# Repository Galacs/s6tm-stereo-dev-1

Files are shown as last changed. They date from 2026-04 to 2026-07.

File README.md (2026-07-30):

# S6TM Stereo Dev 1

ESP32S3 based stereo audio developement board with oled display

## IC List

- ESP32-S3FH4R2 (Main MCU)
- x4 LDL212 (LDOs)
- LM74502H (RPP, OCP)
- TPS629330 (5V out of audio SMPS)
- TLV320AIC (CODEC)
- TPA3116D2 (2x 30W audio amplifier)
- TPA3116D2 (OLED display)

## Top preview



## Preview 3d render



## Pictures

## Pin definitions

```c
#define SD_DAT0_PIN 33
#define SD_DAT1_PIN 47
#define SD_DAT2_PIN 37
#define SD_DAT3_PIN 36
#define SD_CLK_PIN 34
#define SD_CMD_PIN 35

#define SW_A_PIN 2
#define BTN_A_PIN 4
#define BTN_B_PIN 3

#define PG_PIN 5
#define VSNS_PIN 6

#define I2C_SDA_PIN 8
#define I2C_SCL_PIN 7

#define ENC_A_PIN 38
#define ENC_B_PIN 39
#define ENC_SW 40

#define FAULTZ_PIN 17
#define MUTE_PIN 21

#define GPIO1_PIN 15
#define RESET_PIN 16
#define BCLK_PIN 10
#define DOUT_PIN 13
#define DIN_PIN 12
#define MCLK_PIN 9
#define WCLK_PIN 11
```

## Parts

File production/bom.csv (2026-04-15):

Designator | Footprint | Quantity | Value | LCSC Part #
AE1 | Johanson_2450AT18x100 | 1 | Antenna | C127629
C1, C3 | 0402 | 2 | 1p2 | C76899
C10, C14, C22, C46, C47, C48, C6, C8, C9 | 0402 | 9 | 0u1 | C307331
C11, C24, C28, C29, C32, C33, C4, C40, C41, C42, C43, C54, C55, C56, C57, C62, C7 | 0402 | 17 | 1u | C52923
C12, C13 | 0402 | 2 | 12p | C1547
C15, C16, C17, C18, C19, C20, C5 | 0402 | 7 | 10u | C15525
C21, C23, C44, C45, C50, C51, C52, C53 | 0805 | 8 | 10u | C440198
C25, C26 | CP_Elec_8x10 | 2 | 220u | C136294
C27, C30, C31, C34, C35, C36, C37, C38, C39, C49 | 0402 | 10 | 220n | C16772
C58, C59, C60, C61 | 0402 | 4 | 4u7 | C23733
D1 | D_SOD-123 | 1 | BZT52B3V3 | C19077392
D10, D6, D8 | Diode_DFN1006 | 3 | H5VU10U | C22395519
D11, D13 | 0805 | 2 | RED | NCD0805R1
D12 | D_SMB | 1 | D_TVS | C2925441
D14, D9 | D_SMA | 2 | D_Schottky | C22452
D2, D3, D5 | 0805 | 3 | GREEN | C2297
D4, D7 | 0603 | 2 | WHITE | C2290
J1 | microSD_Hanbo_TF012 | 1 | Micro_SD_Card_Det1 | C410350
J3 | USB_C_Receptacle_HRO_TYPE-C-31-M-12 | 1 | USB_C_Receptacle_USB2.0_14P | C393939
J4 | JST_PH_B2B-PH-K_1x02_P2.00mm_Vertical | 1 | Conn_01x02
J5 | Jack_3.5mm_KoreanHropartsElec_PJ-320D-4A_Horizontal | 1 | AudioJack4 | C521460
J6, J7 | JST_XH_B2B-XH-A_1x02_P2.50mm_Vertical | 2 | Conn_01x02
L1 | 0402 | 1 | 6n8 | C77110
L10 | L_Sunlord_MWSA0402S | 1 | 3u3 | C167207
L3, L4 | 0402 | 2 | 2n7 | C77108
L5 | 0402 | 1 | 24n | C167472
L6, L7, L8, L9 | L_Vishay_IHLP-4040 | 4 | 10u | C845065
MK1 | JST_PH_B2B-PH-K_1x02_P2.00mm_Vertical | 1 | Microphone
Q1, Q2 | Vishay_PowerPAK_1212-8_Single | 2 | Q_NMOS | C111309
R1 | 0402 | 1 | 0 | C17168
R10, R11, R12, R18, R19, R7, R8, R9 | 0402 | 8 | 22 | C25092
R13, R14, R16, R17, R2, R20, R22, R3, R34, R35, R4, R40, R44, R45, R47, R5, R6 | 0402 | 17 | 10k | C25744
R15 | 0402 | 1 | 470 | C25117
R21, R42 | 0402 | 2 | 1k | C11702
R23, R24, R25, R26, R27, R28, R29, R30, R36, R43 | 0402 | 10 | 5k1 | C25905
R31 | 0402 | 1 | 2k2 | C25879
R33 | 0603 | 1 | 5k6 | C23189
R37 | 0402 | 1 | 100k | C25741
R38 | 0603 | 1 | 3k6 | C22980
R39 | 0402 | 1 | 52k3 | C26982
R41 | 0402 | 1 | 2k4 | C25882
R46, R48 | 0402 | 2 | 5k6 | C25908
SW1 | SW_SPDT_Shouhan_MSK12C02 | 1 | SW_SPDT | C431540
SW2, SW3 | SW_SPST_Omron_B3F-40xx | 2 | SW_Push | C84931
SW5, SW6 | SW_SPST_TS-1088-xR020 | 2 | SW_Push | C720477
SW7 | RotaryEncoder_Alps_EC11E-Switch_Vertical_H20mm | 1 | RotaryEncoder_Switch | C370970
TP10, TP11, TP13, TP14, TP19, TP3, TP4, TP5, TP6, TP7, TP8, TP9 | TestPoint_Keystone_5015_Micro_Mini | 12 | TestPoint | C2906768
U1 | QFN-56-1EP_7x7mm_P0.4mm_EP4x4mm_ThermalVias | 1 | ESP32-S3FN8 | C3013940
U10, U7, U8, U9 | DFN-6-1EP_2x2mm_P0.5mm_ST | 4 | LDL212PVR | C2969922
U3 | VQFN-32-1EP_5x5mm_P0.5mm_EP3.5x3.5mm | 1 | TLV320AIC3100 | C478458
U4 | HTSSOP-32-1EP_6.1x11mm_P0.65mm_EP5.2x11mm_Mask4.11x4.36mm_ThermalVias | 1 | TPA3118D2 | C46497
U5 | SOT-583-8 | 1 | TPS62933O | C6290372
U6 | SOT-23-THIN-8 | 1 | LM74502 | C3236215
Y1 | Crystal_SMD_2016-4Pin_2.0x1.6mm | 1 | 48M | C7206306

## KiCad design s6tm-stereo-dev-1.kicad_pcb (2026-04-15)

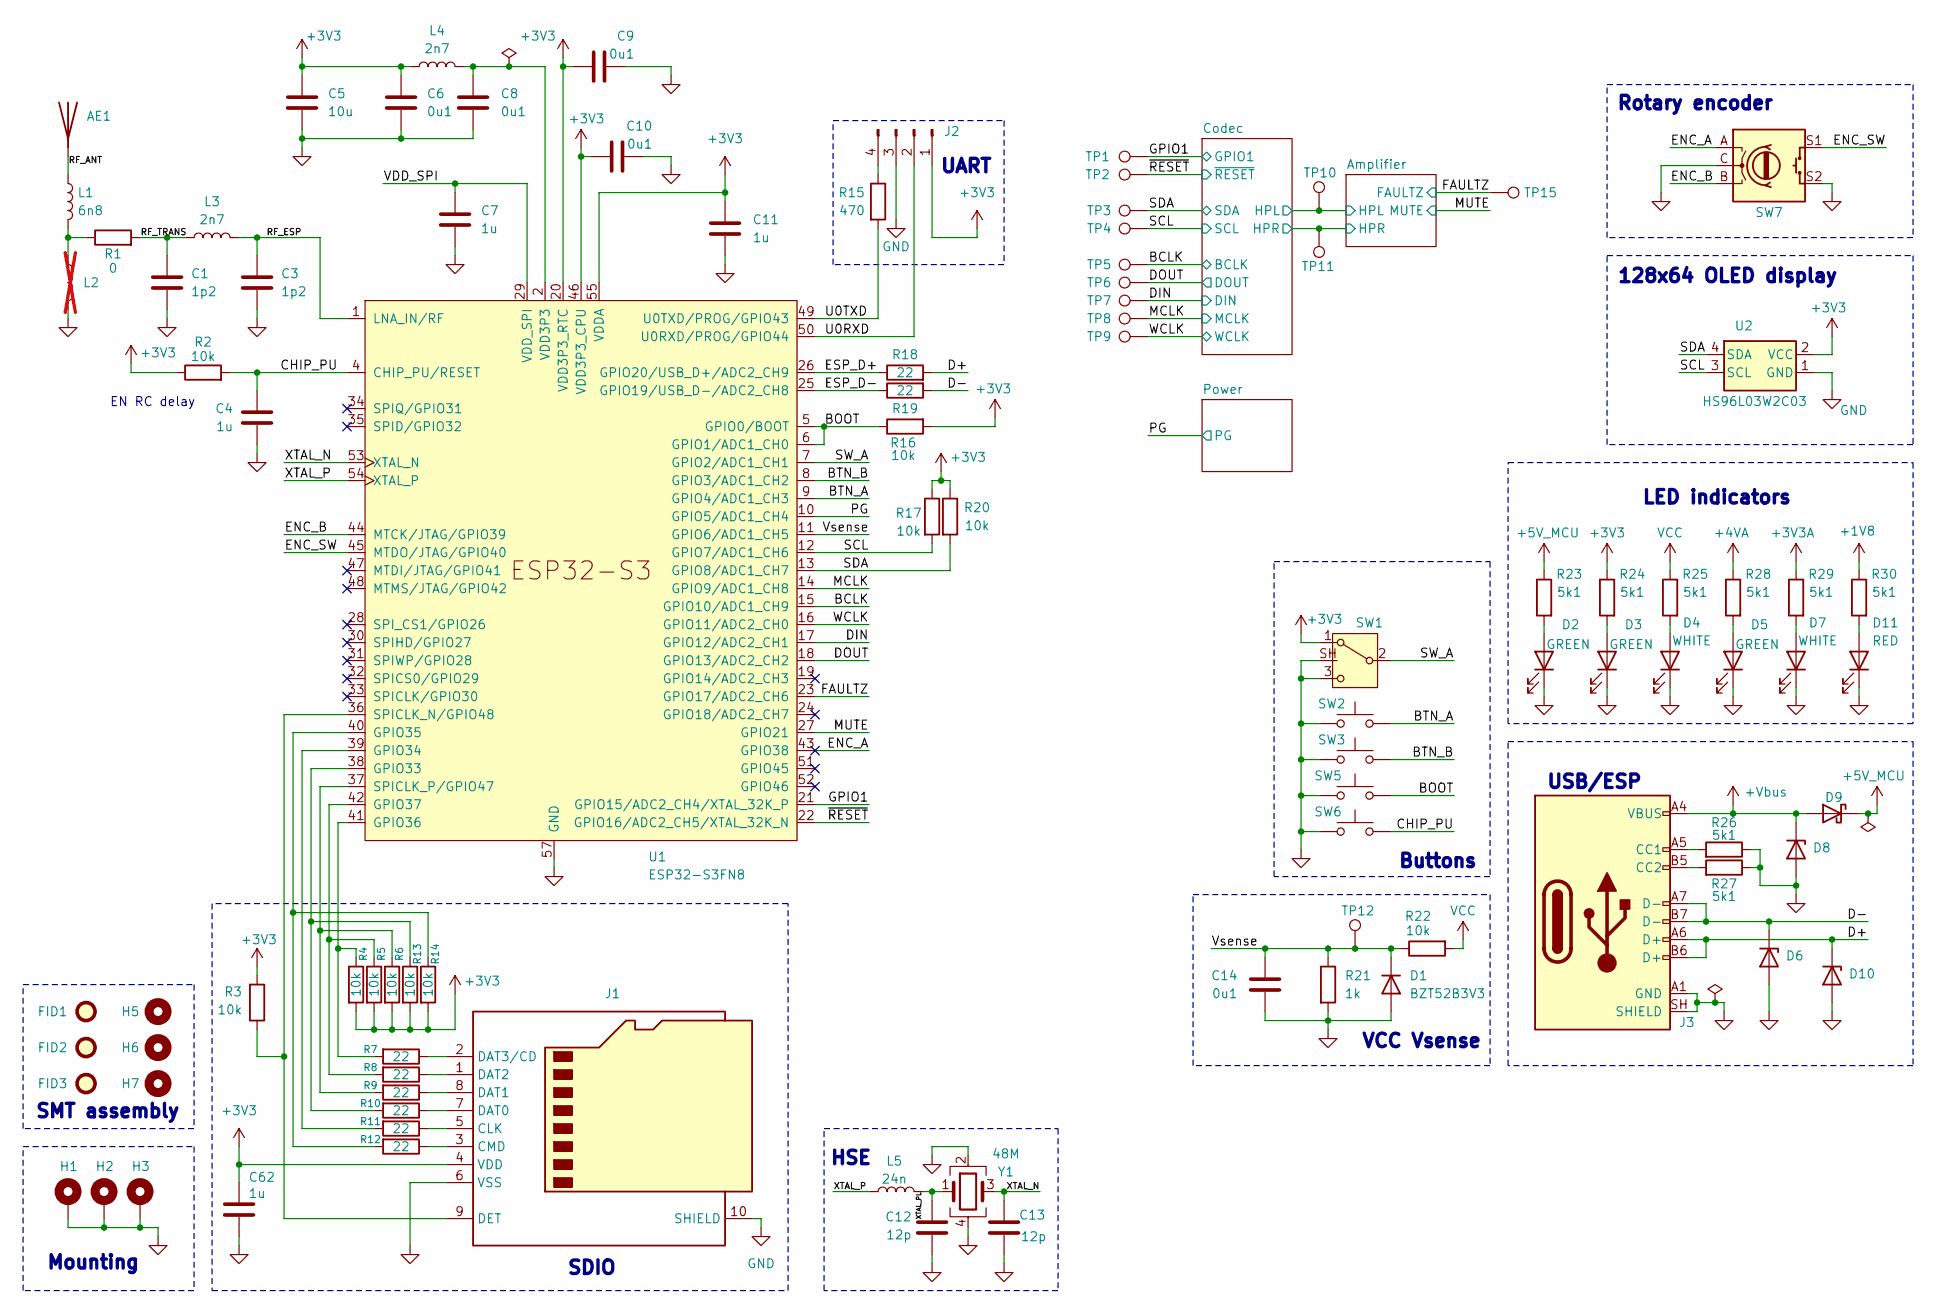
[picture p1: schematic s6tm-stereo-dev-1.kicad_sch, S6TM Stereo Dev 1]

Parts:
AE1: Antenna; Johanson_2450AT18x100; Manufacturer Part Number RFANT3216120A5T; JLCPCB Part # C127629
C1, C3: 1p2; C_0402_1005Metric; Manufacturer Part Number GJM1555C1H1R2WB01D; JLCPCB Part # C76899
C4, C7, C11, C62: 1u; C_0402_1005Metric; Manufacturer Part Number CL05A105KA5NQNC; JLCPCB Part # C52923
C5: 10u; C_0402_1005Metric; Manufacturer Part Number CL05A106MQ5NUNC; JLCPCB Part # C15525
C6, C8, C9, C10, C14: 0u1; C_0402_1005Metric; Manufacturer Part Number CL05B104KB54PNC; JLCPCB Part # C307331
C12, C13: 12p; C_0402_1005Metric; Manufacturer Part Number 0402CG120J500NT; JLCPCB Part # C1547
D1: BZT52B3V3; D_SOD-123; Manufacturer Part Number BZT52B3V3; JLCPCB Part # C19077392
D2, D3, D5: GREEN; LED_0805_2012Metric; Manufacturer Part Number KT-0805G; JLCPCB Part # C2297
D4, D7: WHITE; LED_0603_1608Metric; Manufacturer Part Number KT-0603W; JLCPCB Part # C2290
D6, D8, D10: H5VU10U; Diode_DFN1006; Manufacturer Part Number H5VU10U; JLCPCB Part # C22395519
D9: D_Schottky; D_SMA; Manufacturer Part Number SS54; JLCPCB Part # C22452
D11: RED; LED_0805_2012Metric; Manufacturer Part Number NCD0805R1; JLCPCB Part # NCD0805R1
FID1, FID2, FID3: Fiducial; Fiducial_1mm_Mask2mm
H1, H2, H3: MountingHole_Pad; MountingHole_3.2mm_M3_Pad_Via
H5, H6, H7: MountingHole; ToolingHole_1.152mm
J1: Micro_SD_Card_Det1; microSD_Hanbo_TF012; Manufacturer Part Number TF-012; JLCPCB Part # C410350
J2: Conn_01x04_Pin; PinHeader_1x04_P2.54mm_Vertical
J3: USB_C_Receptacle_USB2.0_14P; USB_C_Receptacle_HRO_TYPE-C-31-M-12; Manufacturer Part Number TYPE-C16PIN; JLCPCB Part # C393939
L1: 6n8; L_0402_1005Metric; Manufacturer Part Number LQG15HS6N8J02D; JLCPCB Part # C77110
L2: L; L_0402_1005Metric; not fitted
L3, L4: 2n7; L_0402_1005Metric; Manufacturer Part Number LQG15HS2N7S02D; JLCPCB Part # C77108
L5: 24n; L_0402_1005Metric; Manufacturer Part Number LQW15AN24NG00D; JLCPCB Part # C167472
R1: 0; R_0402_1005Metric; Manufacturer Part Number 0402WGF0000TCE; JLCPCB Part # C17168
R2, R3, R4, R5, R6, R13, R14, R16, R17, R20, R22: 10k; R_0402_1005Metric; Manufacturer Part Number 0402WGF1002TCE; JLCPCB Part # C25744
R7, R8, R9, R10, R11, R12, R18, R19: 22; R_0402_1005Metric; Manufacturer Part Number 0402WGF220JTCE; JLCPCB Part # C25092
R15: 470; R_0402_1005Metric; Manufacturer Part Number 0402WGF4700TCE; JLCPCB Part # C25117
R21: 1k; R_0402_1005Metric; Manufacturer Part Number 0402WGF1001TCE; JLCPCB Part # C11702
R23, R24, R25, R26, R27, R28, R29, R30: 5k1; R_0402_1005Metric; Manufacturer Part Number 0402WGF5101TCE; JLCPCB Part # C25905
SW1: SW_SPDT; SW_SPDT_Shouhan_MSK12C02; Manufacturer Part Number MSK12C02; JLCPCB Part # C431540
SW2, SW3: SW_Push; SW_SPST_Omron_B3F-40xx; Manufacturer Part Number B3F-4055; JLCPCB Part # C84931
SW5, SW6: SW_Push; SW_SPST_TS-1088-xR020; Manufacturer Part Number TS-1088-AR02016; JLCPCB Part # C720477
SW7: RotaryEncoder_Switch; RotaryEncoder_Alps_EC11E-Switch_Vertical_H20mm; Manufacturer Part Number EC11E15244G1; JLCPCB Part # C370970
TP1, TP2, TP12, TP15: TestPoint; TestPoint_Pad_D2.0mm
TP3, TP4, TP5, TP6, TP7, TP8, TP9, TP10, TP11: TestPoint; TestPoint_Keystone_5015_Micro_Mini; Manufacturer Part Number 5015; JLCPCB Part # C2906768
U1: ESP32-S3FN8; QFN-56-1EP_7x7mm_P0.4mm_EP4x4mm_ThermalVias; Manufacturer Part Number ESP32-S3FH4R2; JLCPCB Part # C3013940
U2: HS96L03W2C03
Y1: 48M; Crystal_SMD_2016-4Pin_2.0x1.6mm; Manufacturer Part Number R940000096; JLCPCB Part # C7206306

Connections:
+1V8: R30.1; also elsewhere on the board
+3V3: C5.1, C6.1, C9.1, C10.1, C11.1, C62.1, J1.4 (VDD), J2.1, L4.1, R2.1, R3.2, R4.2, R5.2, R6.2, R13.2, R14.2, R16.2, R17.1, R20.1, R24.1, SW1.1 (A), U1.20 (VDD3P3_RTC), U1.46 (VDD3P3_CPU), U1.55 (VDDA), U1.56 (VDDA), U2.2 (VCC); also elsewhere on the board
+3V3A: R29.1; also elsewhere on the board
+4VA: R28.1; also elsewhere on the board
+5V_MCU: D9.1 (K), R23.1; also elsewhere on the board
+Vbus: D8.1 (K), D9.2 (A), J3.A4 (VBUS), J3.A9 (VBUS), J3.B4 (VBUS), J3.B9 (VBUS)
/Amplifier/HPL: TP10.1 (1_1); also elsewhere on the board
/Amplifier/HPR: TP11.1 (1_1); also elsewhere on the board
/BCLK: TP5.1 (1_1), U1.15 (GPIO10/ADC1_CH9); also elsewhere on the board
/BOOT: R16.1, SW5.2, U1.5 (GPIO0/BOOT), U1.6 (GPIO1/ADC1_CH0)
/BTN_A: SW2.1, U1.9 (GPIO4/ADC1_CH3)
/BTN_B: SW3.1, U1.8 (GPIO3/ADC1_CH2)
/CHIP_PU: C4.1, R2.2, SW6.2, U1.4 (CHIP_PU/RESET)
/D+: D10.1 (K), J3.A6 (D+), J3.B6 (D+), R18.2
/D-: D6.1 (K), J3.A7 (D-), J3.B7 (D-), R19.2
/DIN: TP7.1 (1_1), U1.17 (GPIO12/ADC2_CH1); also elsewhere on the board
/DOUT: TP6.1 (1_1), U1.18 (GPIO13/ADC2_CH2); also elsewhere on the board
/ENC_A: SW7.A, U1.43 (GPIO38)
/ENC_B: SW7.B, U1.44 (MTCK/JTAG/GPIO39)
/ENC_SW: SW7.S1, U1.45 (MTDO/JTAG/GPIO40)
/ESP_D+: R18.1, U1.26 (GPIO20/USB_D+/ADC2_CH9)
/ESP_D-: R19.1, U1.25 (GPIO19/USB_D-/ADC2_CH8)
/FAULTZ: TP15.1 (1_1), U1.23 (GPIO17/ADC2_CH6); also elsewhere on the board
/GPIO1: TP1.1 (1_1), U1.21 (GPIO15/ADC2_CH4/XTAL_32K_P); also elsewhere on the board
/MCLK: TP8.1 (1_1), U1.14 (GPIO9/ADC1_CH8); also elsewhere on the board
/MUTE: U1.27 (GPIO21); also elsewhere on the board
/PG: U1.10 (GPIO5/ADC1_CH4); also elsewhere on the board
/RF_ANT: AE1.1 (A_1), L1.1
/RF_ESP: C3.1, L3.2, U1.1 (LNA_IN/RF)
/RF_TRANS: C1.1, L3.1, R1.2
/SCL: R17.2, TP4.1 (1_1), U1.12 (GPIO7/ADC1_CH6), U2.3 (SCL); also elsewhere on the board
/SDA: R20.2, TP3.1 (1_1), U1.13 (GPIO8/ADC1_CH7), U2.4 (SDA); also elsewhere on the board
/SW_A: SW1.2 (B), U1.7 (GPIO2/ADC1_CH1)
/U0RXD: J2.2, U1.50 (U0RXD/PROG/GPIO44)
/U0TXD: R15.2, U1.49 (U0TXD/PROG/GPIO43)
/VDD_SPI: C7.1, U1.29 (VDD_SPI)
/Vsense: C14.1, D1.1 (K), R21.1, R22.1, TP12.1 (1_1), U1.11 (GPIO6/ADC1_CH5)
/WCLK: TP9.1 (1_1), U1.16 (GPIO11/ADC2_CH0); also elsewhere on the board
/XTAL_N: C13.1, U1.53 (XTAL_N), Y1.3
/XTAL_P: L5.1, U1.54 (XTAL_P)
/XTAL_PL: C12.2, L5.2, Y1.1
/~RESET: TP2.1 (1_1), U1.22 (GPIO16/ADC2_CH5/XTAL_32K_N); also elsewhere on the board
GND: C1.2, C3.2, C4.2, C5.2, C6.2, C7.2, C8.2, C9.2, C10.2, C11.2, C12.1, C13.2, C14.2, C62.2, D1.2 (A), D2.1 (K), D3.1 (K), D4.1 (K), D5.1 (K), D6.2 (A), D7.1 (K), D8.2 (A), D10.2 (A), D11.1 (K), H1.1 (1_1), H2.1 (1_1), H3.1 (1_1), J1.6 (VSS), J1.10 (SHIELD), J2.3, J3.A1 (GND), J3.A12 (GND), J3.B1 (GND), J3.B12 (GND), J3.SH (SHIELD), L2.2, R21.2, R26.1, R27.1, SW1.3 (C), SW1.SH, SW2.2, SW3.2, SW5.1, SW6.1, SW7.C, SW7.S2, U1.57 (GND), U2.1 (GND), Y1.2, Y1.4; also elsewhere on the board
unnamed: D2.2 (A), R23.2
unnamed: D3.2 (A), R24.2
unnamed: D4.2 (A), R25.2
unnamed: D5.2 (A), R28.2
unnamed: D7.2 (A), R29.2
unnamed: D11.2 (A), R30.2
unnamed: J1.5 (CLK), R11.1
unnamed: J1.3 (CMD), R12.1
unnamed: J1.7 (DAT0), R10.1
unnamed: J1.8 (DAT1), R9.1
unnamed: J1.1 (DAT2), R8.1
unnamed: J1.2 (DAT3/CD), R7.1
unnamed: J1.9 (DET), R3.1, U1.36 (SPICLK_N/GPIO48)
unnamed: J2.4, R15.1
unnamed: J3.A5 (CC1), R26.2
unnamed: J3.B5 (CC2), R27.2
unnamed: L1.2, L2.1, R1.1
unnamed: R10.2, R13.1, U1.38 (GPIO33)
unnamed: R11.2, U1.39 (GPIO34)
unnamed: R12.2, R14.1, U1.40 (GPIO35)
unnamed: R4.1, R7.2, U1.41 (GPIO36)
unnamed: R5.1, R8.2, U1.42 (GPIO37)
unnamed: R6.1, R9.2, U1.37 (SPICLK_P/GPIO47)
VCC: R22.2, R25.1; also elsewhere on the board
VDD3P3: C8.1, L4.2, U1.2 (VDD3P3), U1.3 (VDD3P3)

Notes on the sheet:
Mounting
Rotary encoder
HSE
UART
128x64 OLED display
SMT assembly
SDIO
EN RC delay
VCC Vsense
USB/ESP
Buttons
LED indicators

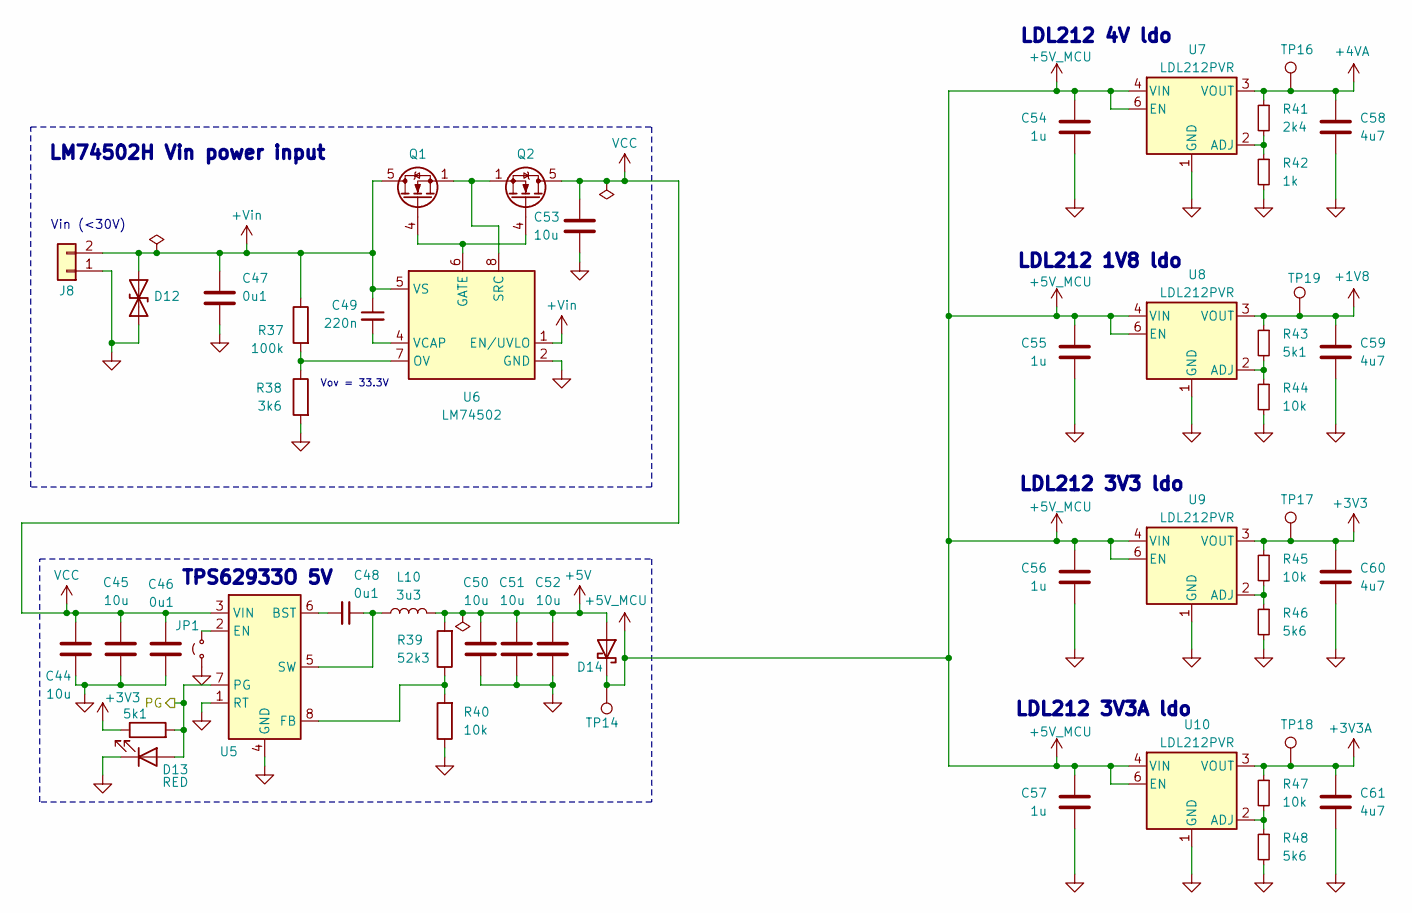
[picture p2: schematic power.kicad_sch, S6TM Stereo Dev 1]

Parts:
C44, C45, C50, C51, C52, C53: 10u; C_0805_2012Metric; Manufacturer Part Number GRM21BR61H106KE43L; JLCPCB Part # C440198
C46, C47, C48: 0u1; C_0402_1005Metric; Manufacturer Part Number CL05B104KB54PNC; JLCPCB Part # C307331
C49: 220n; C_0402_1005Metric; Manufacturer Part Number CL05B224KO5NNNC; JLCPCB Part # C16772
C54, C55, C56, C57: 1u; C_0402_1005Metric; Manufacturer Part Number CL05A105KA5NQNC; JLCPCB Part # C52923
C58, C59, C60, C61: 4u7; C_0402_1005Metric; Manufacturer Part Number CL05A475MP5NRNC; JLCPCB Part # C23733
D12: D_TVS; D_SMB; Manufacturer Part Number SMBJ30CA; JLCPCB Part # C2925441
D13: RED; LED_0805_2012Metric; Manufacturer Part Number NCD0805R1; JLCPCB Part # NCD0805R1
D14: D_Schottky; D_SMA; Manufacturer Part Number SS54; JLCPCB Part # C22452
J8: Conn_01x02; TerminalBlock_Phoenix_MKDS-1,5-2-5.08_1x02_P5.08mm_Horizont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
JP1: Jumper_2_Small_Open; PinHeader_1x02_P2.54mm_Vertical
L10: 3u3; L_Sunlord_MWSA0402S; Manufacturer Part Number FXL0420-3R3-M; JLCPCB Part # C167207
Q1, Q2: Q_NMOS; Vishay_PowerPAK_1212-8_Single; Manufacturer Part Number SIS412DN-T1-GE3; JLCPCB Part # C111309
R36, R43: 5k1; R_0402_1005Metric; Manufacturer Part Number 0402WGF5101TCE; JLCPCB Part # C25905
R37: 100k; R_0402_1005Metric; Manufacturer Part Number 0402WGF1003TCE; JLCPCB Part # C25741
R38: 3k6; R_0603_1608Metric; Manufacturer Part Number 0603WAF3601T5E; JLCPCB Part # C22980
R39: 52k3; R_0402_1005Metric; Manufacturer Part Number 0402WGF5232TCE; JLCPCB Part # C26982
R40, R44, R45, R47: 10k; R_0402_1005Metric; Manufacturer Part Number 0402WGF1002TCE; JLCPCB Part # C25744
R41: 2k4; R_0402_1005Metric; Manufacturer Part Number 0402WGF2401TCE; JLCPCB Part # C25882
R42: 1k; R_0402_1005Metric; Manufacturer Part Number 0402WGF1001TCE; JLCPCB Part # C11702
R46, R48: 5k6; R_0402_1005Metric; Manufacturer Part Number 0402WGF5601TCE; JLCPCB Part # C25908
TP14, TP19: TestPoint; TestPoint_Keystone_5015_Micro_Mini; Manufacturer Part Number 5015; JLCPCB Part # C2906768
TP16, TP17, TP18: TestPoint; TestPoint_Pad_D2.0mm
U5: TPS62933O; SOT-583-8; Manufacturer Part Number TPS62933ODRLR; JLCPCB Part # C6290372
U6: LM74502; SOT-23-THIN-8; Manufacturer Part Number LM74502DDFR; JLCPCB Part # C3236215
U7, U8, U9, U10: LDL212PVR; DFN-6-1EP_2x2mm_P0.5mm_ST; Manufacturer Part Number LDL212PVR; JLCPCB Part # C2969922

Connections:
+1V8: C59.1, R43.1, TP19.1 (1_1), U8.3 (VOUT); also elsewhere on the board
+3V3: C60.1, R36.1, R45.1, TP17.1 (1_1), U9.3 (VOUT); also elsewhere on the board
+3V3A: C61.1, R47.1, TP18.1 (1_1), U10.3 (VOUT); also elsewhere on the board
+4VA: C58.1, R41.1, TP16.1 (1_1), U7.3 (VOUT); also elsewhere on the board
+5V: C50.1, C51.1, C52.1, D14.2 (A), L10.2, R39.2
+5V_MCU: C54.1, C55.1, C56.1, C57.1, D14.1 (K), TP14.1 (1_1), U7.4 (VIN), U7.6 (EN), U8.4 (VIN), U8.6 (EN), U9.4 (VIN), U9.6 (EN), U10.4 (VIN), U10.6 (EN); also elsewhere on the board
+Vin: C47.1, C49.1, D12.2 (A2), J8.2, Q1.5 (D), R37.1, U6.1 (EN/UVLO), U6.5 (VS)
/PG: D13.2 (A), R36.2, U5.7 (PG); also elsewhere on the board
GND: C44.2, C45.2, C46.2, C47.2, C50.2, C51.2, C52.2, C53.2, C54.2, C55.2, C56.2, C57.2, C58.2, C59.2, C60.2, C61.2, D12.1 (A1), D13.1 (K), J8.1, JP1.1 (A), R38.2, R40.1, R42.2, R44.2, R46.2, R48.2, U5.1 (RT), U5.4 (GND), U6.2 (GND), U7.1 (GND), U8.1 (GND), U9.1 (GND), U10.1 (GND); also elsewhere on the board
unnamed: JP1.2 (B), U5.2 (EN)
unnamed: Q1.4 (G), Q2.4 (G), U6.6 (GATE)
unnamed: C48.2, U5.6 (BST)
unnamed: R39.1, R40.2, U5.8 (FB)
unnamed: C48.1, L10.1, U5.5 (SW)
unnamed: R37.2, R38.1, U6.7 (OV)
unnamed: Q1.1 (S), Q1.2 (S), Q1.3 (S), Q2.1 (S), Q2.2 (S), Q2.3 (S), U6.8 (SRC)
unnamed: C49.2, U6.4 (VCAP)
unnamed: R41.2, R42.1, U7.2 (ADJ)
unnamed: R43.2, R44.1, U8.2 (ADJ)
unnamed: R45.2, R46.1, U9.2 (ADJ)
unnamed: R47.2, R48.1, U10.2 (ADJ)
VCC: C44.1, C45.1, C46.1, C53.1, Q2.5 (D), U5.3 (VIN); also elsewhere on the board

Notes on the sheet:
LDL212 3V3A ldo
Vov = 33.3V
Vin (<30V)
TPS62933O 5V
LDL212 4V ldo
LDL212 1V8 ldo
LM74502H Vin power input
LDL212 3V3 ldo

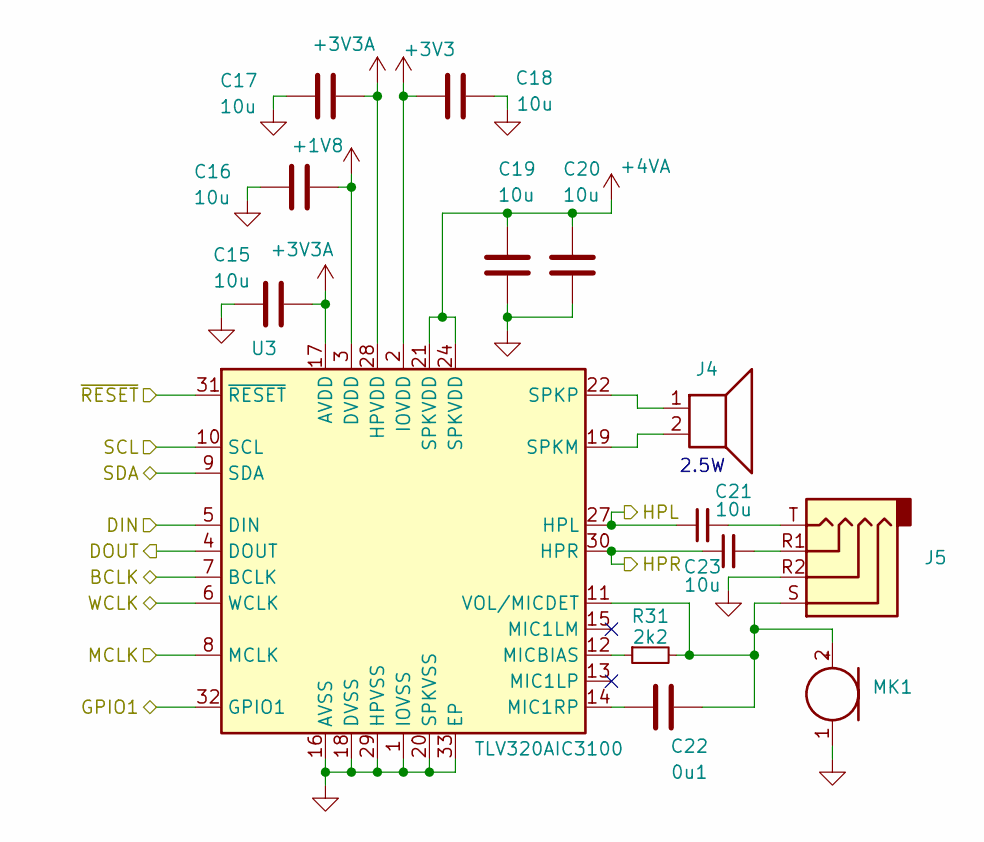
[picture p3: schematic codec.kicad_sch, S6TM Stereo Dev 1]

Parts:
C15, C16, C17, C18, C19, C20: 10u; C_0402_1005Metric; Manufacturer Part Number CL05A106MQ5NUNC; JLCPCB Part # C15525
C21, C23: 10u; C_0805_2012Metric; Manufacturer Part Number GRM21BR61H106KE43L; JLCPCB Part # C440198
C22: 0u1; C_0402_1005Metric; Manufacturer Part Number CL05B104KB54PNC; JLCPCB Part # C307331
J4: Conn_01x02; JST_PH_B2B-PH-K_1x02_P2.00mm_Vertical
J5: AudioJack4; Jack_3.5mm_KoreanHropartsElec_PJ-320D-4A_Horizontal; Manufacturer Part Number PJ-320D; JLCPCB Part # C521460
MK1: Microphone; JST_PH_B2B-PH-K_1x02_P2.00mm_Vertical
R31: 2k2; R_0402_1005Metric; Manufacturer Part Number 0402WGF2201TCE; JLCPCB Part # C25879
U3: TLV320AIC3100; VQFN-32-1EP_5x5mm_P0.5mm_EP3.5x3.5mm; Manufacturer Part Number TLV320AIC3100IRHBR; JLCPCB Part # C478458

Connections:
+1V8: C16.2, U3.3 (DVDD); also elsewhere on the board
+3V3: C18.2, U3.2 (IOVDD); also elsewhere on the board
+3V3A: C15.2, C17.2, U3.17 (AVDD), U3.28 (HPVDD); also elsewhere on the board
+4VA: C19.1, C20.1, U3.21 (SPKVDD), U3.24 (SPKVDD); also elsewhere on the board
/Amplifier/HPL: C21.1, U3.27 (HPL); also elsewhere on the board
/Amplifier/HPR: C23.1, U3.30 (HPR); also elsewhere on the board
/BCLK: U3.7 (BCLK); also elsewhere on the board
/DIN: U3.5 (DIN); also elsewhere on the board
/DOUT: U3.4 (DOUT); also elsewhere on the board
/GPIO1: U3.32 (GPIO1); also elsewhere on the board
/MCLK: U3.8 (MCLK); also elsewhere on the board
/SCL: U3.10 (SCL); also elsewhere on the board
/SDA: U3.9 (SDA); also elsewhere on the board
/WCLK: U3.6 (WCLK); also elsewhere on the board
/~RESET: U3.31 (~RESET); also elsewhere on the board
GND: C15.1, C16.1, C17.1, C18.1, C19.2, C20.2, J5.R2, MK1.1 (-), U3.1 (IOVSS), U3.16 (AVSS), U3.18 (DVSS), U3.20 (SPKVSS), U3.25 (SPKVSS), U3.29 (HPVSS), U3.33 (EP); also elsewhere on the board
unnamed: C21.2, J5.T
unnamed: C23.2, J5.R1
unnamed: J4.1, U3.22 (SPKP), U3.26 (SPKP)
unnamed: J4.2, U3.19 (SPKM), U3.23 (SPKM)
unnamed: C22.2, J5.S, MK1.2 (+), R31.2, U3.11 (VOL/MICDET)
unnamed: C22.1, U3.14 (MIC1RP)
unnamed: R31.1, U3.12 (MICBIAS)

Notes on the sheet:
2.5W

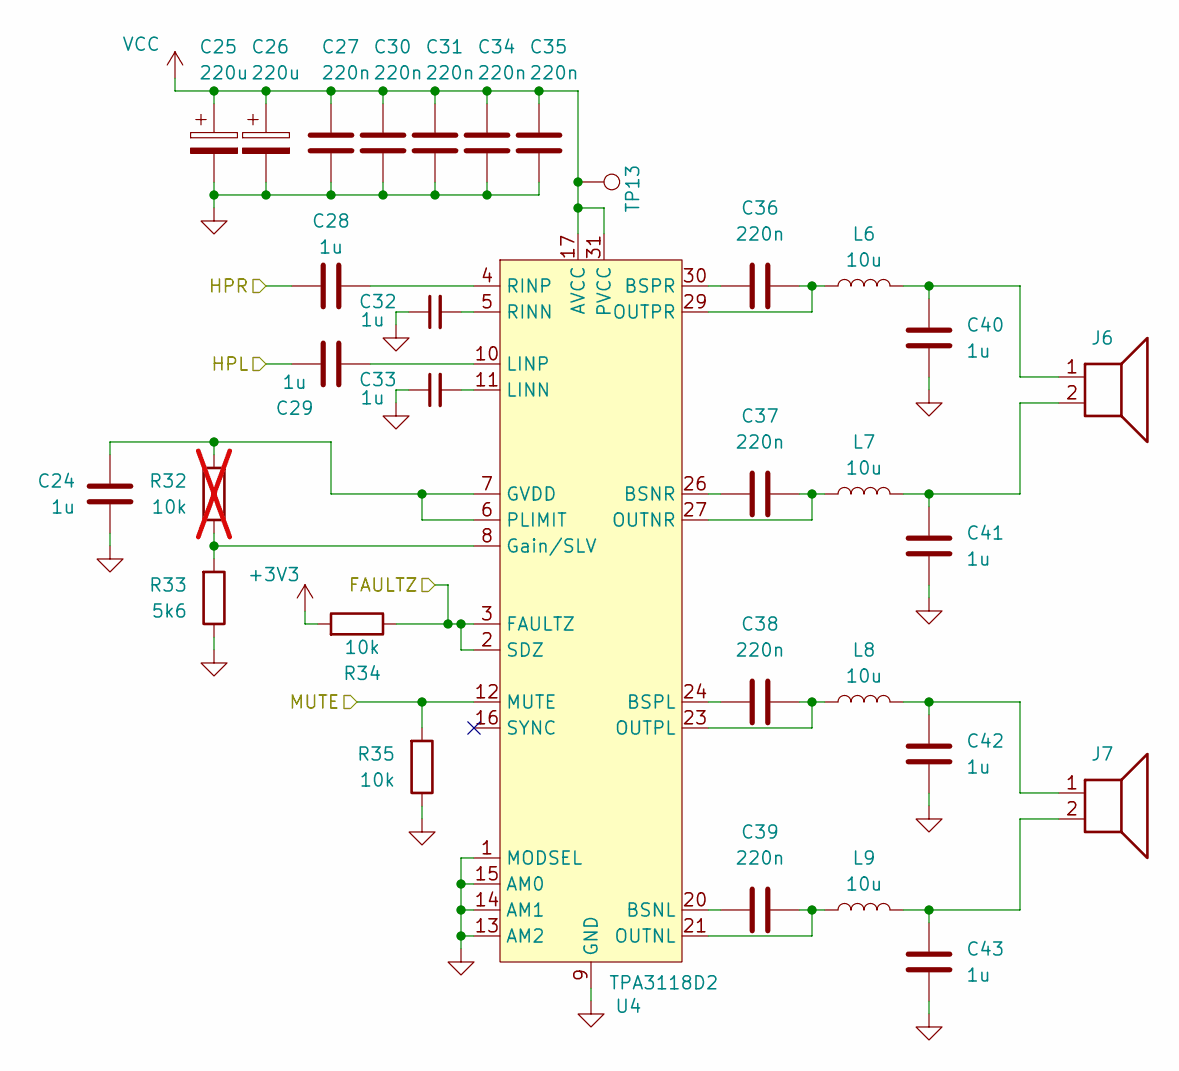
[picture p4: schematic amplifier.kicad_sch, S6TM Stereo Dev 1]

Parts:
C24, C28, C29, C32, C33, C40, C41, C42, C43: 1u; C_0402_1005Metric; Manufacturer Part Number CL05A105KA5NQNC; JLCPCB Part # C52923
C25, C26: 220u; CP_Elec_8x10; Manufacturer Part Number UCD1V221MNL1GS; JLCPCB Part # C136294
C27, C30, C31, C34, C35, C36, C37, C38, C39: 220n; C_0402_1005Metric; Manufacturer Part Number CL05B224KO5NNNC; JLCPCB Part # C16772
J6, J7: Conn_01x02; JST_XH_B2B-XH-A_1x02_P2.50mm_Vertical
L6, L7, L8, L9: 10u; L_Vishay_IHLP-4040; Manufacturer Part Number IHLP4040DZER100M01; JLCPCB Part # C845065
R32: 10k; R_0603_1608Metric; not fitted
R33: 5k6; R_0603_1608Metric; Manufacturer Part Number 0603WAF5601T5E; JLCPCB Part # C23189
R34, R35: 10k; R_0402_1005Metric; Manufacturer Part Number 0402WGF1002TCE; JLCPCB Part # C25744
TP13: TestPoint; TestPoint_Keystone_5015_Micro_Mini; Manufacturer Part Number 5015; JLCPCB Part # C2906768
U4: TPA3118D2; HTSSOP-32-1EP_6.1x11mm_P0.65mm_EP5.2x11mm_Mask4.11x4.36mm_T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; Manufacturer Part Number TPA3118D2DAPR; JLCPCB Part # C46497

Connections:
+3V3: R34.2; also elsewhere on the board
/Amplifier/HPL: C29.2; also elsewhere on the board
/Amplifier/HPR: C28.1; also elsewhere on the board
/FAULTZ: R34.1, U4.2 (SDZ), U4.3 (FAULTZ); also elsewhere on the board
/MUTE: R35.2, U4.12 (MUTE); also elsewhere on the board
GND: C24.2, C25.2, C26.2, C27.2, C30.2, C31.2, C32.1, C33.1, C34.2, C35.2, C40.2, C41.2, C42.2, C43.2, R33.1, R35.1, U4.1 (MODSEL), U4.9 (GND), U4.13 (AM2), U4.14 (AM1), U4.15 (AM0), U4.22 (GND), U4.25 (GND), U4.28 (GND), U4.33 (GND); also elsewhere on the board
unnamed: C40.1, J6.1, L6.2
unnamed: C41.1, J6.2, L7.2
unnamed: C42.1, J7.1, L8.2
unnamed: C43.1, J7.2, L9.2
unnamed: C39.1, U4.20 (BSNL)
unnamed: C37.1, U4.26 (BSNR)
unnamed: C38.1, U4.24 (BSPL)
unnamed: C36.1, U4.30 (BSPR)
unnamed: C24.1, R32.2, U4.6 (PLIMIT), U4.7 (GVDD)
unnamed: R32.1, R33.2, U4.8 (Gain/SLV)
unnamed: C33.2, U4.11 (LINN)
unnamed: C29.1, U4.10 (LINP)
unnamed: C39.2, L9.1, U4.21 (OUTNL)
unnamed: C37.2, L7.1, U4.27 (OUTNR)
unnamed: C38.2, L8.1, U4.23 (OUTPL)
unnamed: C36.2, L6.1, U4.29 (OUTPR)
unnamed: C32.2, U4.5 (RINN)
unnamed: C28.2, U4.4 (RINP)
VCC: C25.1, C26.1, C27.1, C30.1, C31.1, C34.1, C35.1, TP13.1 (1_1), U4.17 (AVCC), U4.18 (PVCC), U4.19 (PVCC), U4.31 (PVCC), U4.32 (PVCC); also elsewhere on the board

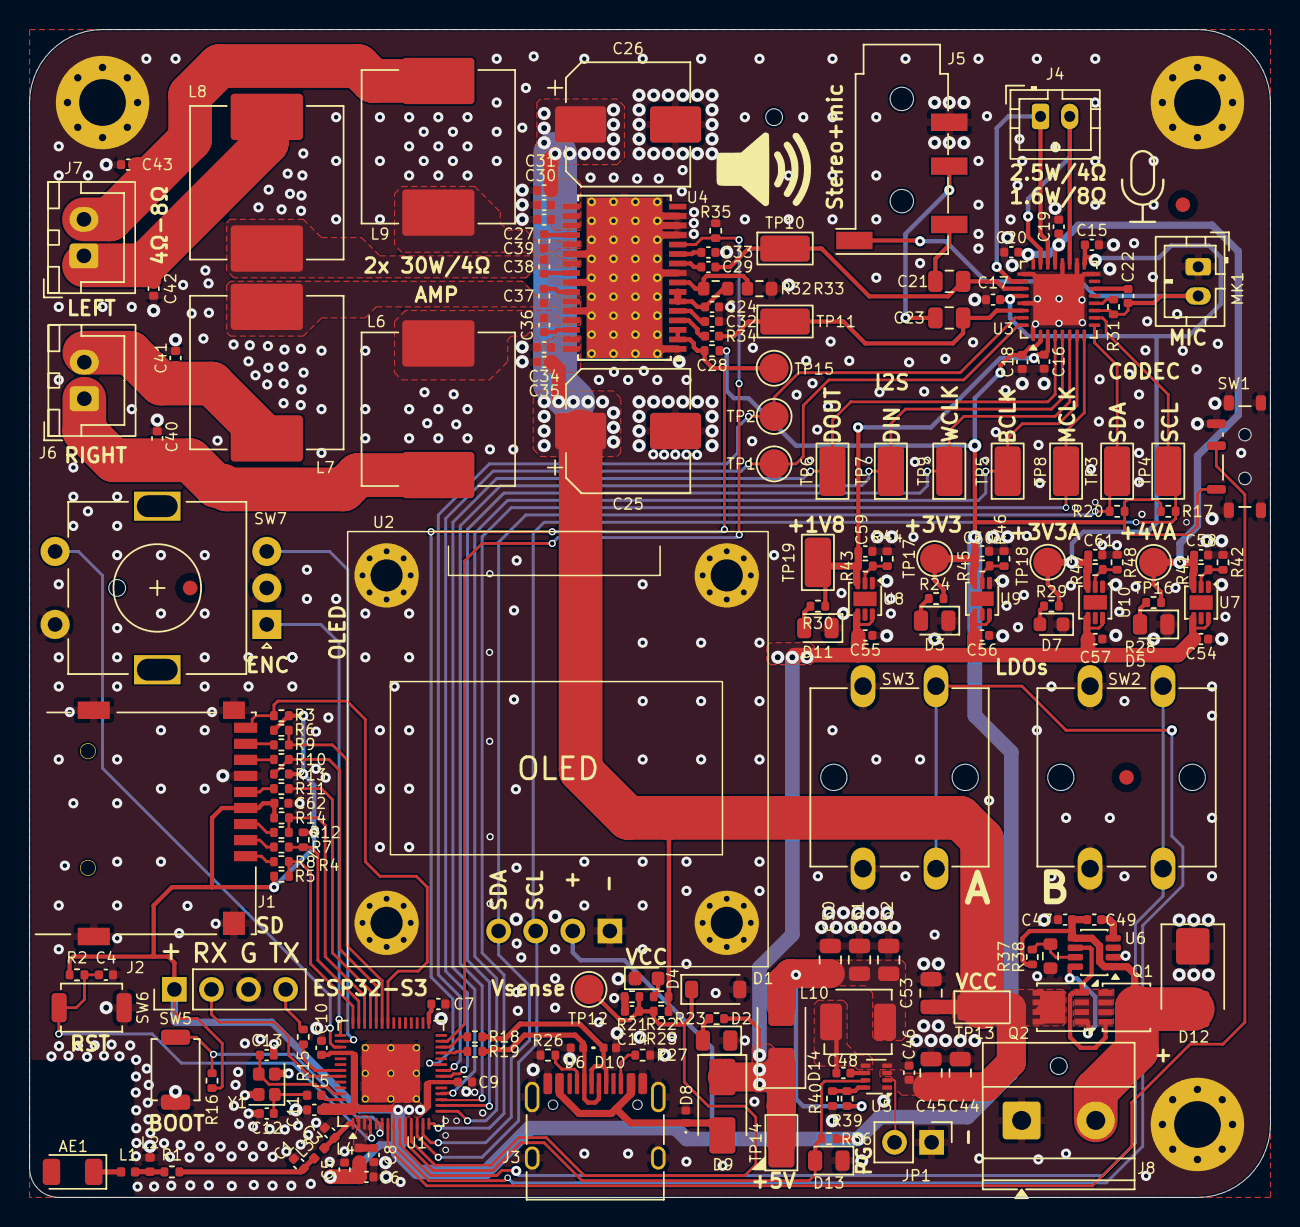
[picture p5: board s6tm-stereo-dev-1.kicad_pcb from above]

Board: 4 copper layers, 85.0 x 80.0 mm, 191 parts (0 on the bottom side), 107 nets.

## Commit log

2026-04-13 schem: import ESP32-S3 mcu
    [s6tm-stereo-dev-1.kicad_sch]
2026-04-13 schem: import HSE oscilator
    [s6tm-stereo-dev-1.kicad_sch]
2026-04-13 schem: import USB-C connector
    [s6tm-stereo-dev-1.kicad_sch]
2026-04-13 schem: import LDL212 3V3 ldo
    [s6tm-stereo-dev-1.kicad_sch]
2026-04-13 schem: add TLV320AIC3100 audio codec and switch to adjustable ldo
    [s6tm-stereo-dev-1.kicad_sch]
2026-04-13 schem: add LDL212 1V8 ldo
    [s6tm-stereo-dev-1.kicad_sch]
2026-04-13 schem: add analog 3v3 ldo
    [s6tm-stereo-dev-1.kicad_sch]
2026-04-13 schem: add speaker 4v ldo (le dernier, je le jure)
    [s6tm-stereo-dev-1.kicad_sch]
2026-04-13 schem: add codec power section
    [codec.kicad_sch, s6tm-stereo-dev-1.kicad_sch]
2026-04-13 schem: remove "extra" 0u1 capacitors from codec
    [codec.kicad_sch]
2026-04-13 schem: add codec surrounding circuitery
    [codec.kicad_sch, s6tm-stereo-dev-1.kicad_sch]
2026-04-13 schem: add hierarchical line output labels to codec
    [codec.kicad_sch, s6tm-stereo-dev-1.kicad_sch]
2026-04-13 schem: add TPA3118D2 amplifier with power section
    [amplifier.kicad_sch, s6tm-stereo-dev-1.kicad_sch]
2026-04-13 schem: add TPA3118 config components
    [amplifier.kicad_sch]
2026-04-14 schem: finish tpa3118 amplifier page
    [amplifier.kicad_sch]
2026-04-14 schem: connect codec to amplifier
    [s6tm-stereo-dev-1.kicad_sch]
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2026-04-14 schem: add TPS62933O 5V OOA buck converter
    [s6tm-stereo-dev-1.kicad_sch]
2026-04-14 schem: add power page and LM74502H Vin power input RPP
    [power.kicad_sch, s6tm-stereo-dev-1.kicad_sch]
2026-04-14 schem: add buck converter PG led
    [power.kicad_sch]
2026-04-14 schem: add led pwr status
    [s6tm-stereo-dev-1.kicad_sch]
2026-04-14 schem: change red led to lower vf
    [power.kicad_sch]
2026-04-14 schem: add power led indicators for all voltage rails
    [s6tm-stereo-dev-1.kicad_sch]
2026-04-14 schem: add PG gpio to buck converter
    [power.kicad_sch, s6tm-stereo-dev-1.kicad_sch]
2026-04-14 schem: add OLED display
    [s6tm-stereo-dev-1.kicad_sch]
2026-04-14 schem: add rotary encoder
    [s6tm-stereo-dev-1.kicad_sch]
2026-04-14 schem: add vcc vsense
    [s6tm-stereo-dev-1.kicad_sch]
2026-04-14 schem: add buck converter disable jumper
    [power.kicad_sch]
2026-04-14 schem: connect pheripherals to mcu gpios
    [power.kicad_sch, s6tm-stereo-dev-1.kicad_sch]
2026-04-14 schem: add sd card slot
    [s6tm-stereo-dev-1.kicad_sch]
2026-04-14 schem: add no connects
    [s6tm-stereo-dev-1.kicad_sch]
2026-04-14 schem: add test points
    [amplifier.kicad_sch, power.kicad_sch, s6tm-stereo-dev-1.kicad_sch]
2026-04-14 schem: add net classes
    [s6tm-stereo-dev-1.kicad_sch]
2026-04-14 schem: add missing footprints
    [amplifier.kicad_sch, codec.kicad_sch, s6tm-stereo-dev-1.kicad_sch]
2026-04-14 schem: add ordering info to BOM
    [amplifier.kicad_sch, codec.kicad_sch, power.kicad_sch]
2026-04-14 schem: run and fix ERC
    [s6tm-stereo-dev-1.kicad_sch]
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2026-04-14 pcb: import 4 layers jlc stackup and constraints
    [s6tm-stereo-dev-1.kicad_pcb]
2026-04-14 pcb: import from schem
    [s6tm-stereo-dev-1.kicad_pcb]
2026-04-14 pcb: add missing 3d models
    [s6tm-stereo-dev-1.kicad_pcb]
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2026-04-14 schem: update esp32s3 footprint
    [s6tm-stereo-dev-1.kicad_sch]
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2026-04-14 schem: add M3 mounting holes
    [s6tm-stereo-dev-1.kicad_pcb, s6tm-stereo-dev-1.kicad_sch]
2026-04-14 schem/pcb: add smt fiducials and tooling holes
    [s6tm-stereo-dev-1.kicad_pcb, s6tm-stereo-dev-1.kicad_sch]
2026-04-14 schem/pcb: remove extra mounting hole
    [s6tm-stereo-dev-1.kicad_pcb, s6tm-stereo-dev-1.kicad_sch]
2026-04-14 pcb: add smps routing
    [s6tm-stereo-dev-1.kicad_pcb]
2026-04-14 schem: switch load switch to always on
    [power.kicad_sch]
2026-04-14 pcb: add LM74502H layout
    [s6tm-stereo-dev-1.kicad_pcb]
2026-04-14 pcb: add usb layout
    [s6tm-stereo-dev-1.kicad_pcb]
2026-04-14 pcb: add LDOs layout
    [power.kicad_sch, s6tm-stereo-dev-1.kicad_pcb]
2026-04-15 pcb: rpp and smps layout refinement
    [power.kicad_sch, s6tm-stereo-dev-1.kicad_pcb]
2026-04-15 pcb: add audio layout
    [amplifier.kicad_sch, codec.kicad_sch, power.kicad_sch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]
2026-04-15 pcb: refine amplifier layout
    [s6tm-stereo-dev-1.kicad_pcb]
2026-04-15 pcb: refine codec layout
    [s6tm-stereo-dev-1.kicad_pcb]
2026-04-15 pcb: add fiducials, tooling holes
    [s6tm-stereo-dev-1.kicad_pcb]
2026-04-15 pcb: refine sd layout
    [s6tm-stereo-dev-1.kicad_pcb, s6tm-stereo-dev-1.kicad_sch]
2026-04-15 pcb: add board outline
    [s6tm-stereo-dev-1.kicad_pcb]
2026-04-15 pcb: add gnd planes
    [s6tm-stereo-dev-1.kicad_pcb]
2026-04-15 pcb: add gnd vias
    [s6tm-stereo-dev-1.kicad_pcb]
2026-04-15 pcb: add grid/place origin
    [s6tm-stereo-dev-1.kicad_pcb]
2026-04-15 pcb: add rf routing
    [s6tm-stereo-dev-1.kicad_pcb]
2026-04-15 pcb: add HSE xtal routing
    [s6tm-stereo-dev-1.kicad_pcb, s6tm-stereo-dev-1.kicad_sch]
2026-04-15 pcb: add uart routing
    [s6tm-stereo-dev-1.kicad_pcb]
2026-04-15 pcb: add sd card routing
    [s6tm-stereo-dev-1.kicad_pcb]
2026-04-15 pcb: add LDOs routing
    [s6tm-stereo-dev-1.kicad_pcb]
2026-04-15 pcb: add codec routing
    [s6tm-stereo-dev-1.kicad_pcb]
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2026-04-15 pcb: add missing 3v3 routing
    [s6tm-stereo-dev-1.kicad_pcb]
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2026-04-15 pcb: run and fix DRC
    [s6tm-stereo-dev-1.kicad_pcb]
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
